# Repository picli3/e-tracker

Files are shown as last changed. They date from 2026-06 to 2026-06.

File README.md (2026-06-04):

# e-track

E-paper based GPS tracker PCB design using KiCad.

## Project Structure

- `e-track.kicad_pcb` - Main PCB layout
- `e-track.kicad_sch` - Schematic file
- `e-track.kicad_pro` - KiCad project file
- `e-track.kicad_prl` - KiCad layout settings
- `Power_Manager.kicad_sch` - Power management module
- `e-paper.kicad_sch` - E-paper display module
- `docs/` - Datasheets and documentation

## Features

- E-paper display interface
- GPS module integration
- Power management system

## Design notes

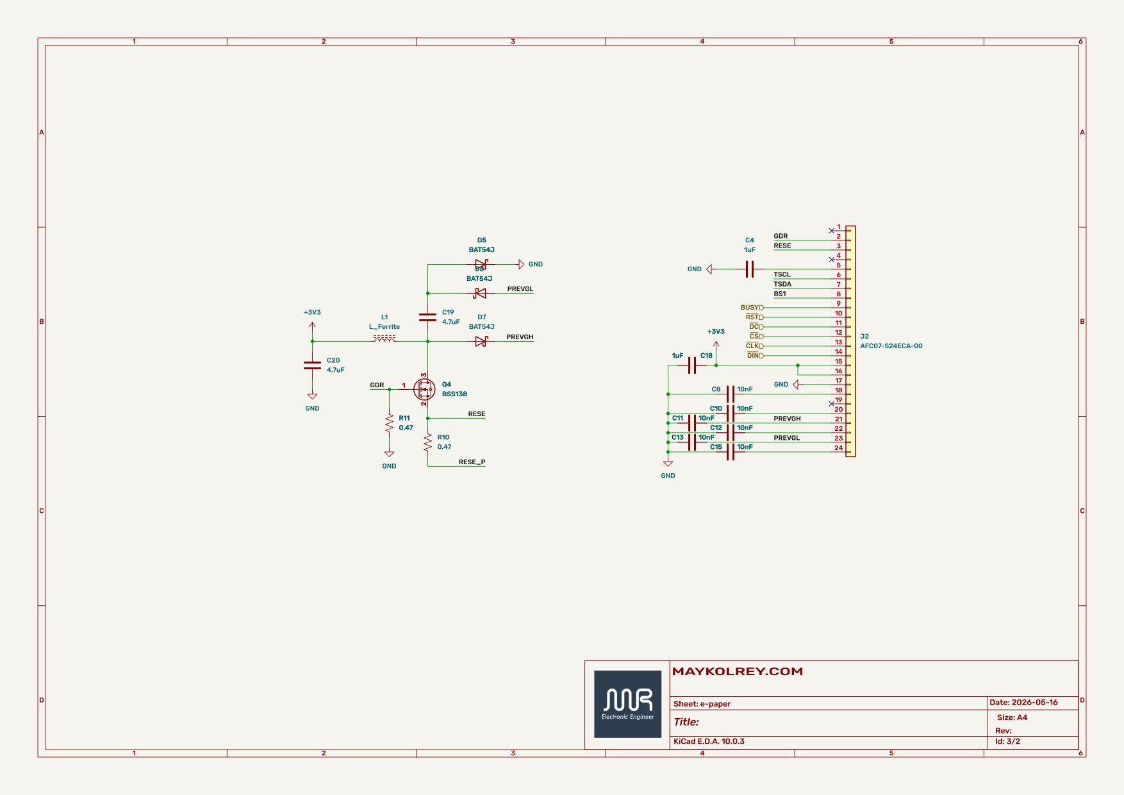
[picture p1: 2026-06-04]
screenshots/e-track-e-paper.png

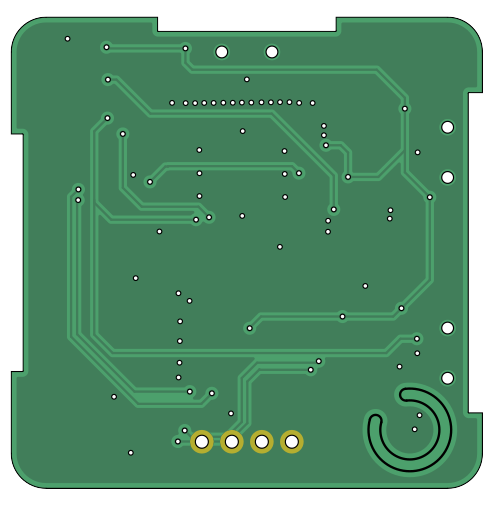
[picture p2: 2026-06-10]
docs/back.png

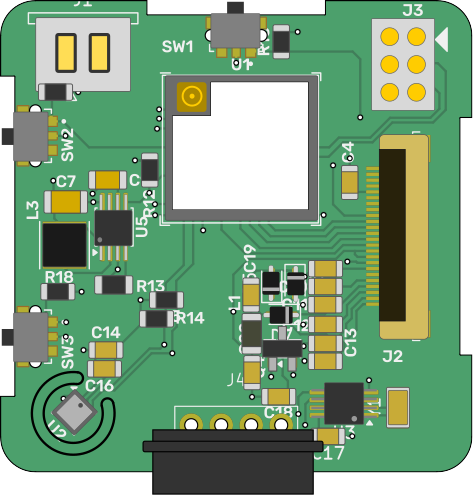
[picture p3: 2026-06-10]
docs/front.png

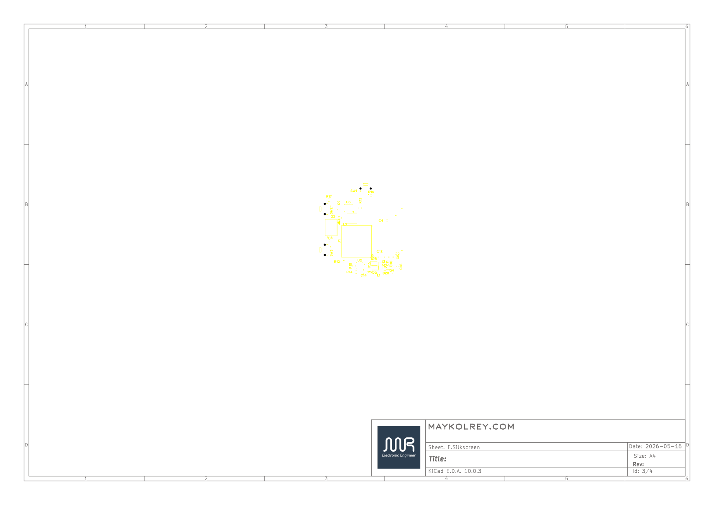
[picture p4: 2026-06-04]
screenshots/e-track-F_Silkscreen.png

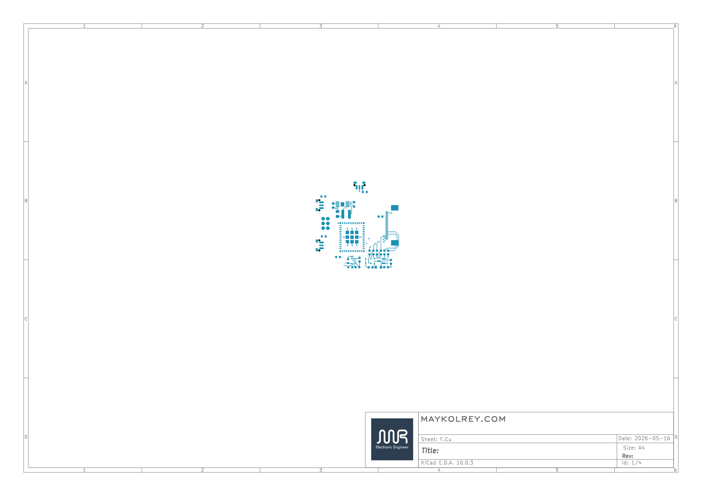
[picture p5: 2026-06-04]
screenshots/e-track-F_Cu.png

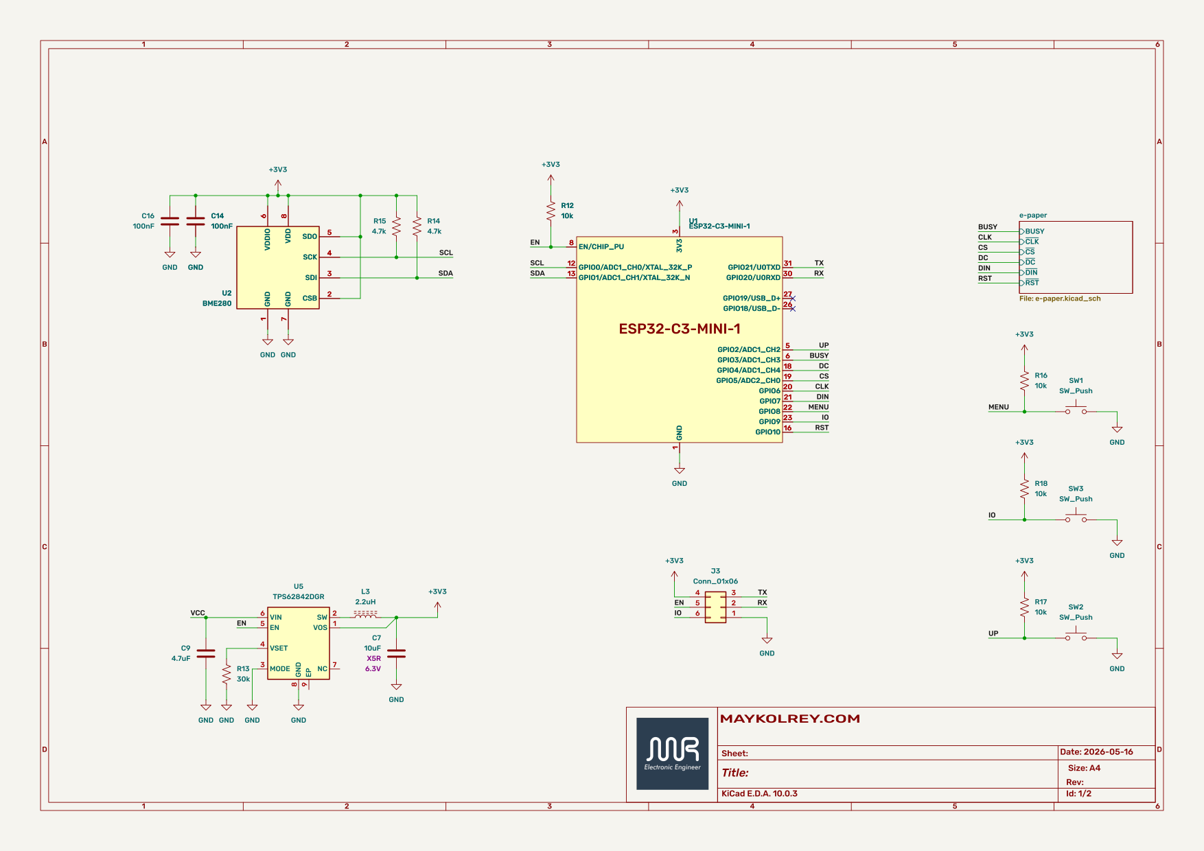
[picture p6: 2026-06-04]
screenshots/e-track.png

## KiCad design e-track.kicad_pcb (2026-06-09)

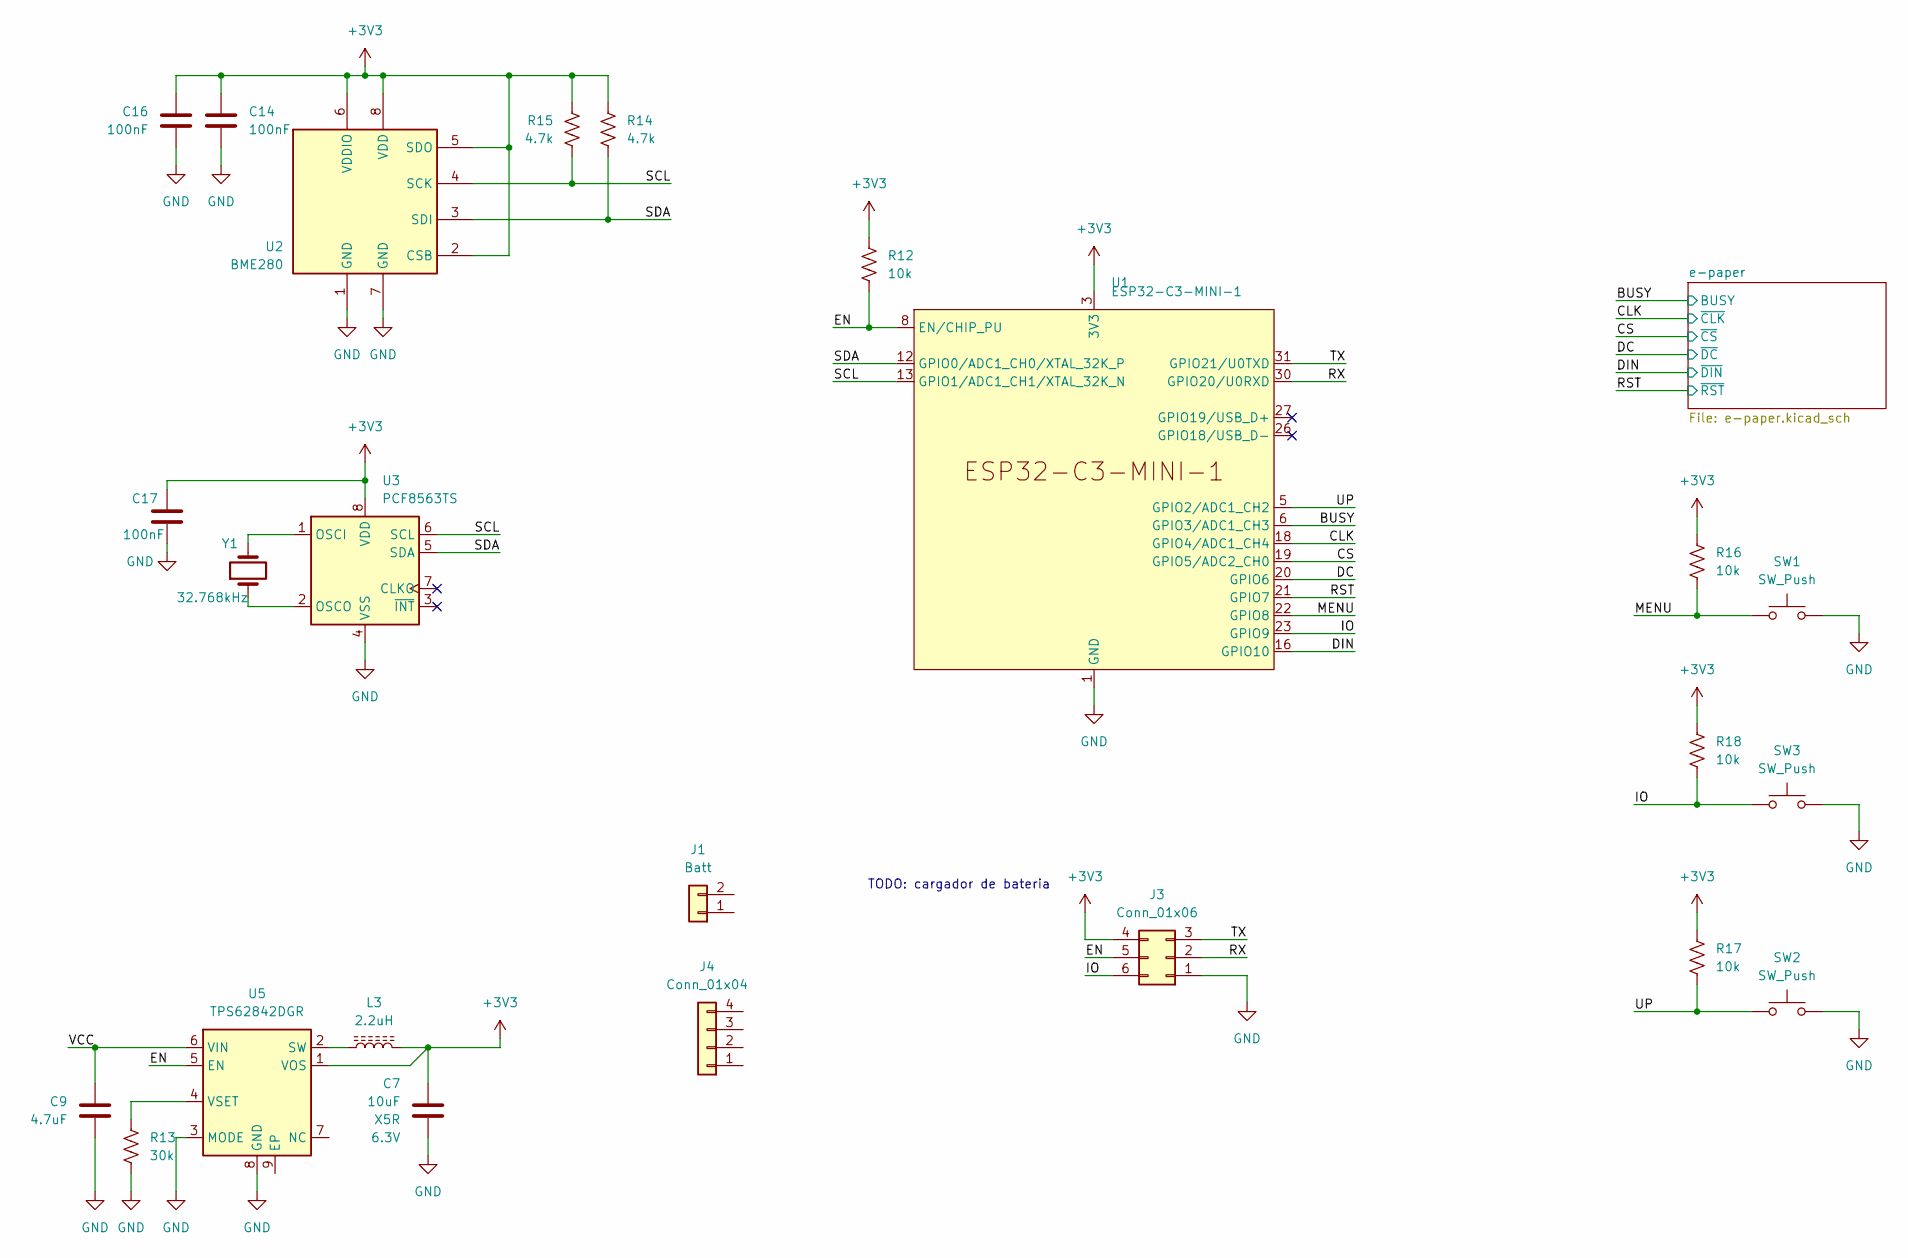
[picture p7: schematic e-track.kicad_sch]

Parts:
C7: 10uF; C_0805_2012Metric_Pad1.18x1.45mm_HandSolder; Mfr. Part CL21A106KPFNNNE; LCSC Part C17024
C9: 4.7uF; C_0603_1608Metric_Pad1.08x0.95mm_HandSolder; Mfr. Part CL10A475KP8NNNC; LCSC Part C1705
C14, C16, C17: 100nF; C_0603_1608Metric
J1: Batt; Samtec_UMPS-02-XX.X-X-V-S_1x02_P2.0mm_Socket
J3: Conn_01x06; pin-programmer
J4: Conn_01x04; pogo-pin-female-4P-2.54
L3: 2.2uH; L_Taiyo-Yuden_MD-4040; Mfr. Part LQH44PN2R2MP0L; LCSC Part C86081
R12, R16, R17, R18: 10k; R_0603_1608Metric
R13: 30k; R_0603_1608Metric_Pad0.98x0.95mm_HandSolder; Mfr. Part 0603WAF3002T5E; LCSC Part C22984
R14, R15: 4.7k; R_0603_1608Metric
SW1, SW2, SW3: SW_Push; SW_TL3340AF160QG
U1: ESP32-C3-MINI-1; ESP32-C3-MINI-1U
U2: BME280; Bosch_LGA-8_2.5x2.5mm_P0.65mm_ClockwisePinNumbering
U3: PCF8563TS; MSOP-8_3x3mm_P0.65mm; Part # PCF8563TS/5,118; LCSC C27397
U5: TPS62842DGR; MSOP-8-1EP_3x3mm_P0.65mm_EP1.5x1.8mm
Y1: 32.768kHz; Crystal_SMD_3215-2Pin_3.2x1.5mm; Part # SC-32S32.768kHz20PPM7pF; LCSC C97604

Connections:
+3V3: C7.1, C14.2, C16.2, C17.2, J3.4, L3.2, R12.2, R14.2, R15.2, R16.2, R17.2, R18.2, U1.3 (3V3), U2.2 (CSB), U2.5 (SDO), U2.6 (VDDIO), U2.8 (VDD), U3.8 (VDD), U5.1 (VOS); also elsewhere on the board
/BUSY: U1.6 (GPIO3/ADC1_CH3); also elsewhere on the board
/CLK: U1.18 (GPIO4/ADC1_CH4); also elsewhere on the board
/CS: U1.19 (GPIO5/ADC2_CH0); also elsewhere on the board
/DC: U1.20 (GPIO6); also elsewhere on the board
/DIN: U1.16 (GPIO10); also elsewhere on the board
/EN: J3.5, R12.1, U1.8 (EN/CHIP_PU), U5.5 (EN)
/IO: J3.6, R18.1, SW3.1, U1.23 (GPIO9)
/MENU: R16.1, SW1.1, U1.22 (GPIO8)
/RST: U1.21 (GPIO7); also elsewhere on the board
/RX: J3.2, U1.30 (GPIO20/U0RXD)
/SCL: R15.1, U1.13 (GPIO1/ADC1_CH1/XTAL_32K_N), U2.4 (SCK), U3.6 (SCL)
/SDA: R14.1, U1.12 (GPIO0/ADC1_CH0/XTAL_32K_P), U2.3 (SDI), U3.5 (SDA)
/TX: J3.3, U1.31 (GPIO21/U0TXD)
/UP: R17.1, SW2.1, U1.5 (GPIO2/ADC1_CH2)
/VCC: C9.1, U5.6 (VIN)
GND: C7.2, C9.2, C14.1, C16.1, C17.1, J3.1, R13.2, SW1.2, SW2.2, SW3.2, U1.1 (GND), U1.2 (GND), U1.11 (GND), U1.14 (GND), U1.36 (GND), U1.37 (GND), U1.38 (GND), U1.39 (GND), U1.40 (GND), U1.41 (GND), U1.42 (GND), U1.43 (GND), U1.44 (GND), U1.45 (GND), U1.46 (GND), U1.47 (GND), U1.48 (GND), U1.49 (GND), U1.50 (GND), U1.51 (GND), U1.52 (GND), U1.53 (GND), U2.1 (GND), U2.7 (GND), U3.4 (VSS), U5.3 (MODE), U5.8 (GND); also elsewhere on the board
unnamed: U3.1 (OSCI), Y1.2
unnamed: U3.2 (OSCO), Y1.1
unnamed: L3.1, U5.2 (SW)
unnamed: R13.1, U5.4 (VSET)

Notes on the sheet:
TODO: cargador de bateria

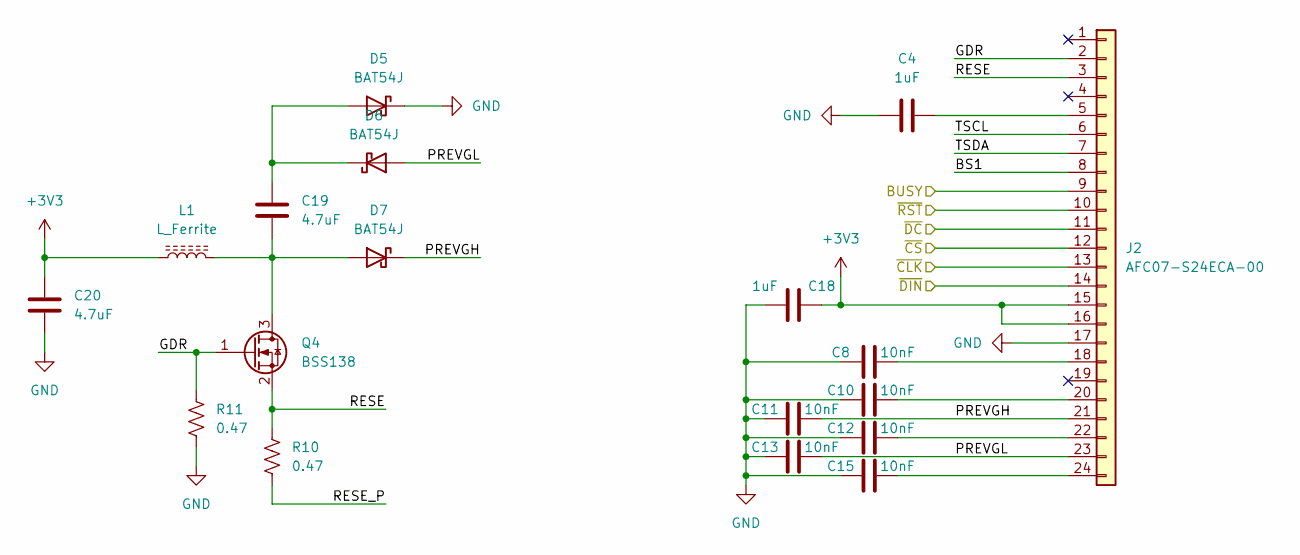
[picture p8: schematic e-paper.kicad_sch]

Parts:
C4, C18: 1uF; C_0603_1608Metric
C8, C10, C11, C12, C13, C15: 10nF; C_0603_1608Metric
C19, C20: 4.7uF; C_0603_1608Metric
D5, D6, D7: BAT54J; D_SOD-323F; LCSC C82046
J2: AFC07-S24ECA-00; TE_2-1734839-4_1x24-1MP_P0.5mm_Horizontal; Part # AFC07-S24ECA-00; LCSC C262643
L1: L_Ferrite; L_0805_2012Metric
Q4: BSS138; SOT-23
R10, R11: 0.47

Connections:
+3V3: C18.2, C20.1, J2.15, J2.16, L1.1; also elsewhere on the board
/BUSY: J2.9; also elsewhere on the board
/CLK: J2.13; also elsewhere on the board
/CS: J2.12; also elsewhere on the board
/DC: J2.11; also elsewhere on the board
/DIN: J2.14; also elsewhere on the board
/RST: J2.10; also elsewhere on the board
/e-paper/BS1: J2.8
/e-paper/GDR: J2.2, Q4.1 (G), R11.1
/e-paper/PREVGH: C11.2, D7.1 (K), J2.21
/e-paper/PREVGL: C13.2, D6.2 (A), J2.23
/e-paper/RESE: J2.3, Q4.2 (S), R10.1
/e-paper/TSCL: J2.6
/e-paper/TSDA: J2.7
GND: C4.1, C8.1, C10.1, C11.1, C12.1, C13.1, C15.1, C18.1, C20.2, D5.1 (K), J2.17, R11.2; also elsewhere on the board
unnamed: C19.1, D5.2 (A), D6.1 (K)
unnamed: C19.2, D7.2 (A), L1.2, Q4.3 (D)
unnamed: C4.2, J2.5
unnamed: C8.2, J2.18
unnamed: C10.2, J2.20
unnamed: C12.2, J2.22
unnamed: C15.2, J2.24

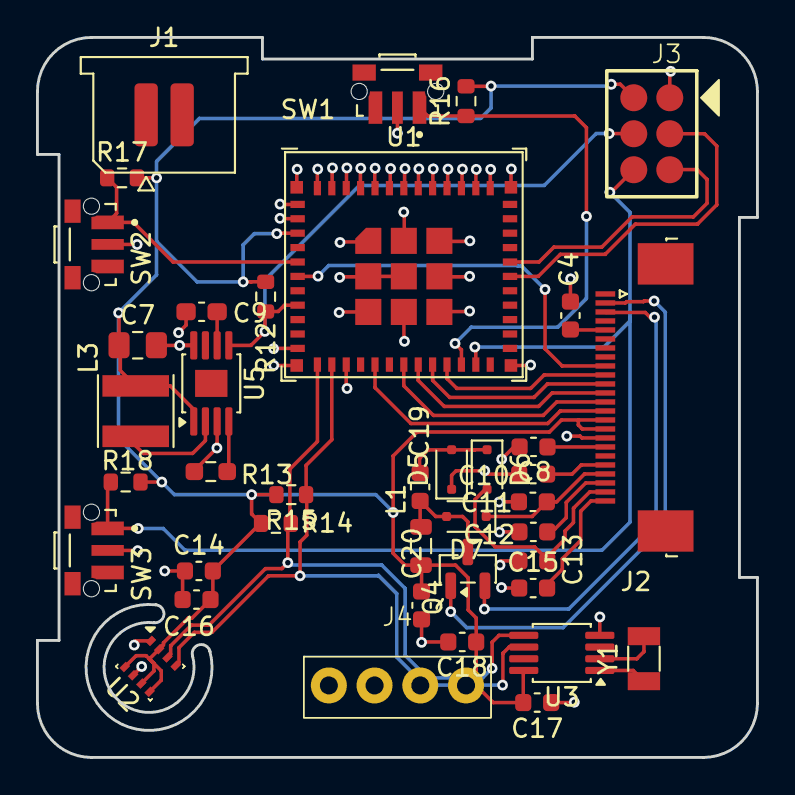
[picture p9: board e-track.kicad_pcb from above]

Board: 2 copper layers, 40.0 x 40.0 mm, 40 parts (0 on the bottom side), 32 nets.

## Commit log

2026-06-04 Initial commit: e-track PCB project
    [Power_Manager.kicad_sch, e-paper.kicad_sch, e-track.kicad_pcb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]
2026-06-04 Add PCB design screenshots
2026-06-04 Update PCB design and add SVG exports, improve gitignore
    [e-track.kicad_pcb, e-track.kicad_sch]
2026-06-09 agregando conector y RTC
    [e-track.kicad_pcb, e-track.kicad_sch]
